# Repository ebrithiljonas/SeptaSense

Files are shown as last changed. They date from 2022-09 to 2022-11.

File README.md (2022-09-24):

# Septa Sense

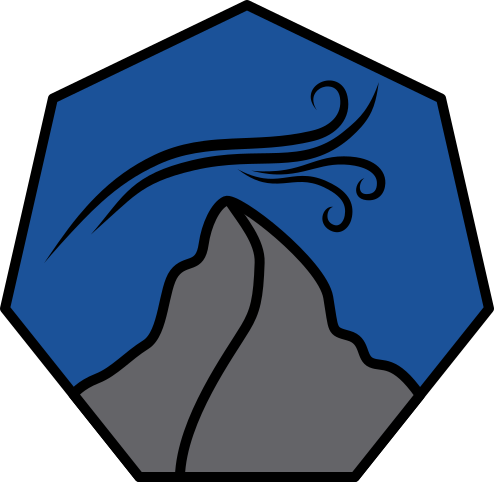
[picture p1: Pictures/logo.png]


Septa Sense in an Open Source and Open Hardware IoT air quality sensor, based on an ESP32 running ESPHome. It features a rim of RGB-LEDs around the top which indicate the quality of the air. Measurements can be seen either on in the integrated display or over Home Assistant. The unit is powered with a USB-C plug on the backside.

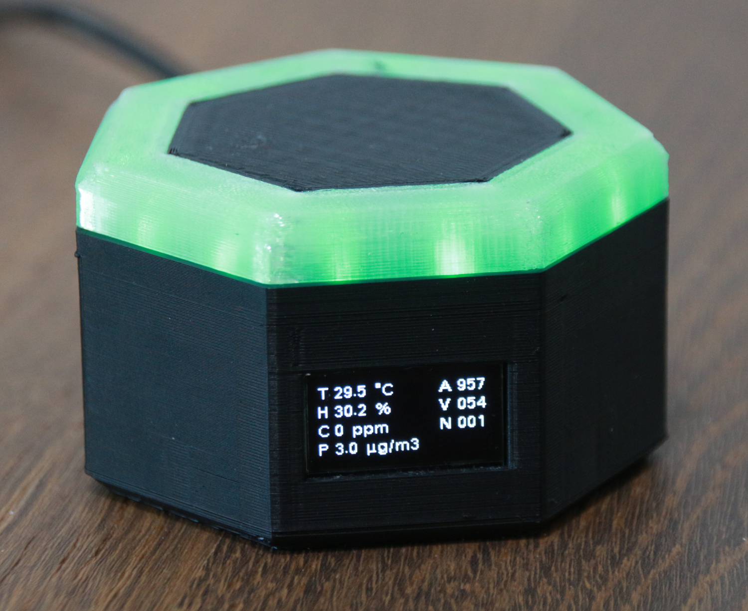
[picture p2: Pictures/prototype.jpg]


## Capabilities
- Temperature (0 - 50°C ± 0.5°C)
- Humidity (0 - 100% ± 4.5%)
- VOC (1 - 500 Index ± 5 Index)
- NOx (1 - 500 Index ± 10 Index)
- Particulate Matter (0 - 1000 μg/m³ ± 10%)
- CO2 (400 - 5000 ppm ± (40 ppm + 5%))
- Pressure (300 - 1250 hPa ± 0.5 hPa)

### Sensors
- [SEN55](https://sensirion.com/products/catalog/SEN55/)
- [SCD41](https://sensirion.com/products/catalog/SCD41/)
- [BMP388](https://www.bosch-sensortec.com/products/environmental-sensors/pressure-sensors/bmp388/)

## Mainboard

The mainboard is a custom PCB which holds the ESP32 chip, the BMP388 and SCD41 sensors and the RGB LEDs. The SEN55 sensor and the display are connected to it with a cable that is directly soldered to the board. It gets power via the USB-C plug over a cable with a JST XH connector that is mounted on the PCB.

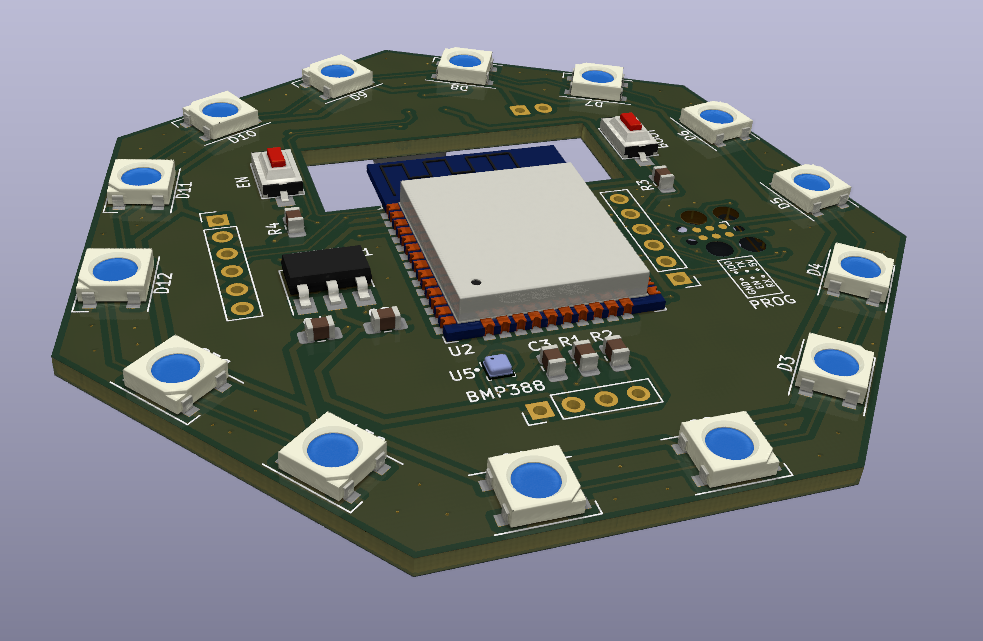
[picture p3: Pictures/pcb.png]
pcb


## 3D-Print

The case consists of 5 different 3D printed parts. Recommended print settings are:

- Case Bottom
  - Layer height: 0.2 mm
  - Infill: 10 %
  - Support: Yes
  - Support overhang: 80°
- Case Top
  - Layer height: 0.2 mm
  - Infill: 10 %
  - Support: No
- LED Ring
  - Layer height: 0.2 mm
  - Infill: 20 %
  - Support: No
- SEN55 Bracket
  - Layer height: 0.1 mm
  - Infill: 20 %
  - Support: No
- Display Fixture
  - Layer height: 0.2 mm
  - Infill: 20 %
  - Support: No

## BOM
- 1x [Mainboard](#mainboard)
- 1x [SEN55](https://sensirion.com/products/catalog/SEN55/)
- 1x [SCD41](https://sensirion.com/products/catalog/SCD41/)
- 1x Display [SD1306 128x64](https://www.aliexpress.com/item/32638662748.html)
- 1x [USB-C Connector](https://www.aliexpress.com/item/1005001714874457.html)
- 1x Micro JST GH 6 pin Cable
- 1x JST XH 2 Pin Cable
- 1x Dupont Female 4 pin Cable
- 2x M3x5,7-OD 4,6 heat inserts
- 2x M3x10 countersunk screws
- 1x [Set of 3D-Prints](#3d-print)

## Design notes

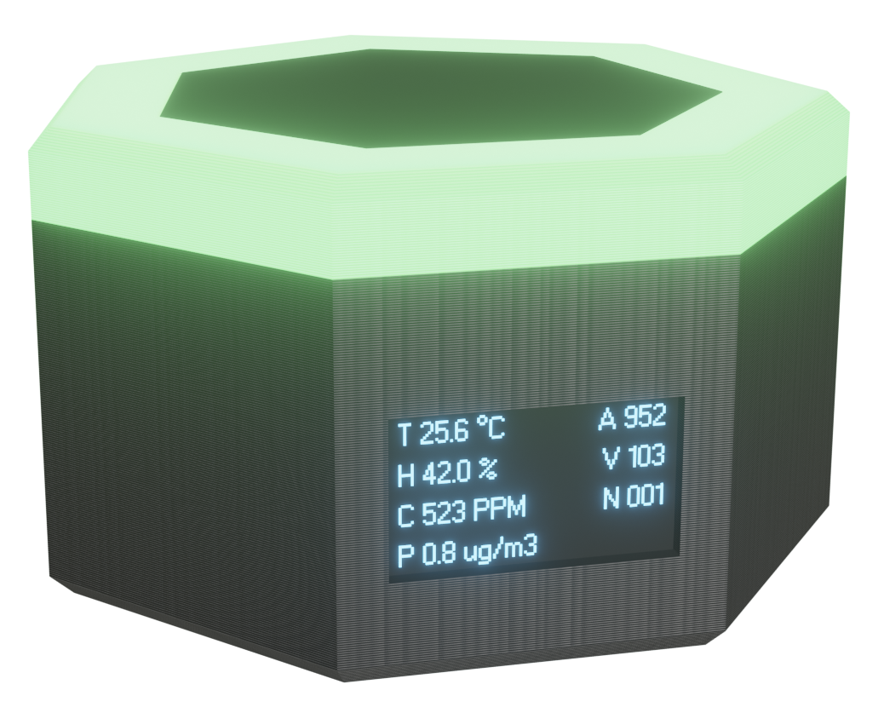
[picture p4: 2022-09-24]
Pictures/render.png

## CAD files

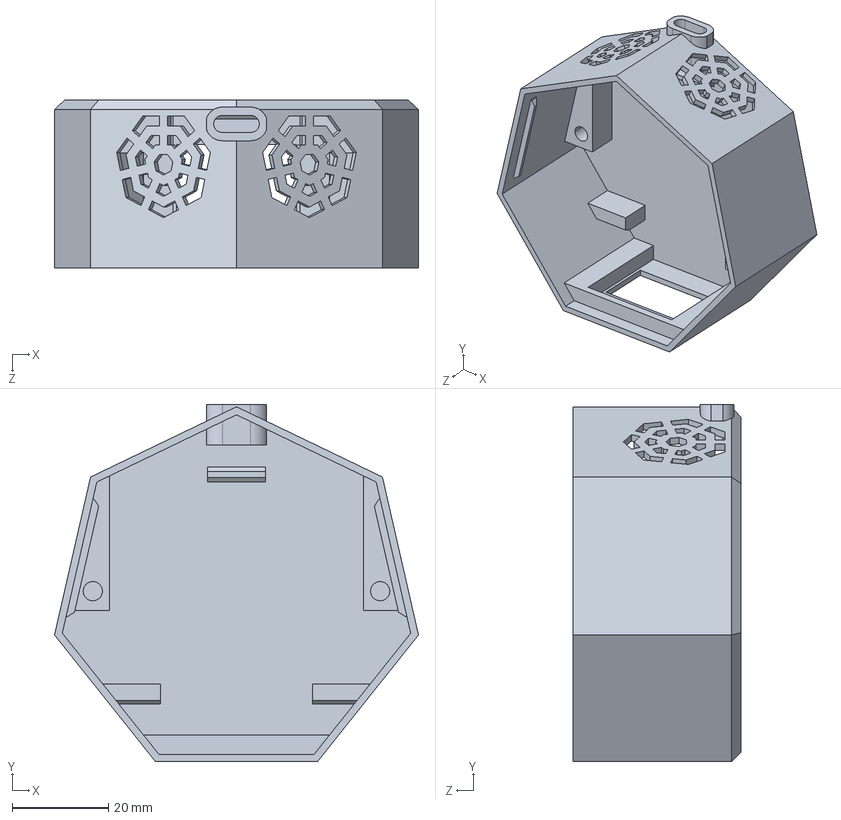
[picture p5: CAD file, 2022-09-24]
CAD/Case Bottom.STEP
75.7 x 74.3 x 35.0 mm

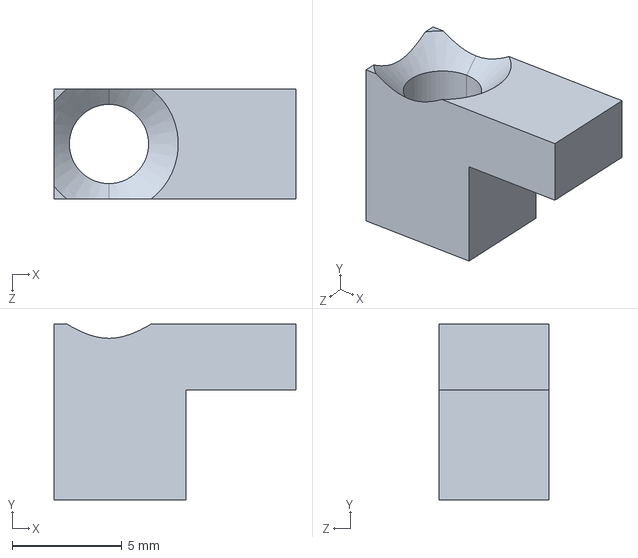
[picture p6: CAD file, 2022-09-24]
CAD/SEN55 Bracket.STEP
11.0 x 8.00 x 5.00 mm

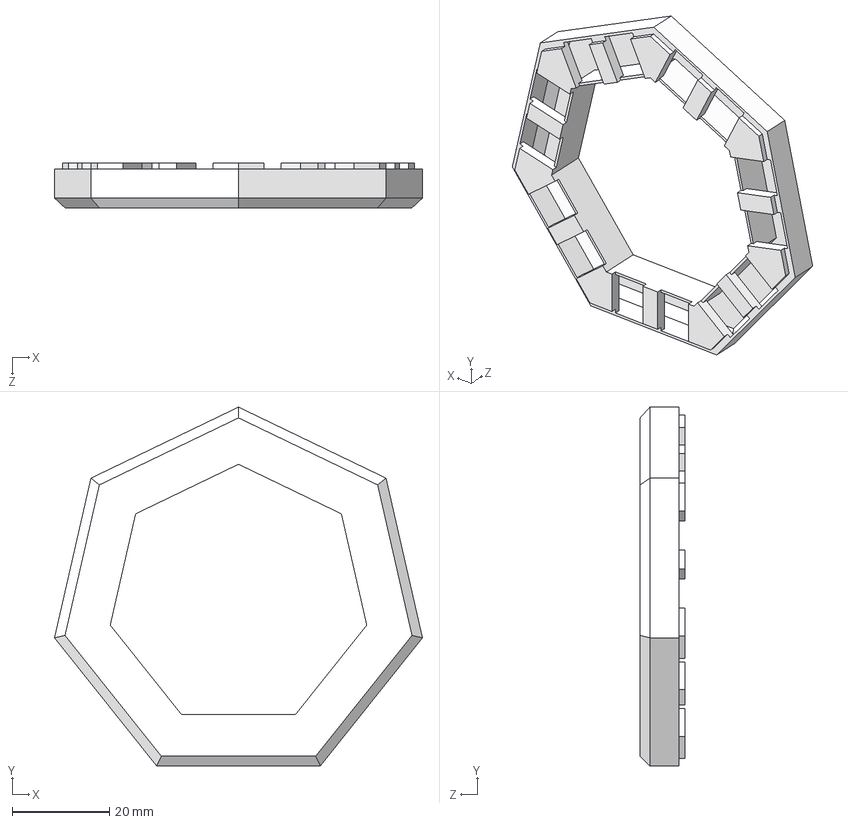
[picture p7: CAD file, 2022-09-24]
CAD/Case Top LED-Ring.STEP
75.7 x 73.8 x 9.20 mm

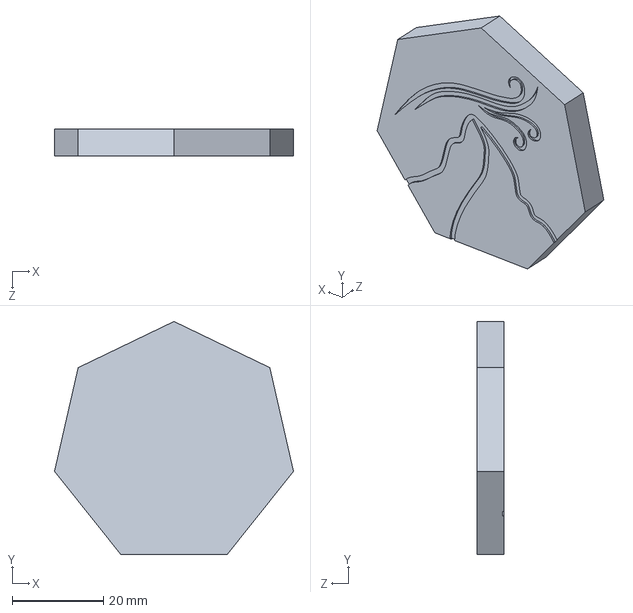
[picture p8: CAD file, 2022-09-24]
CAD/Case Top Logo.STEP
52.4 x 51.1 x 6.00 mm

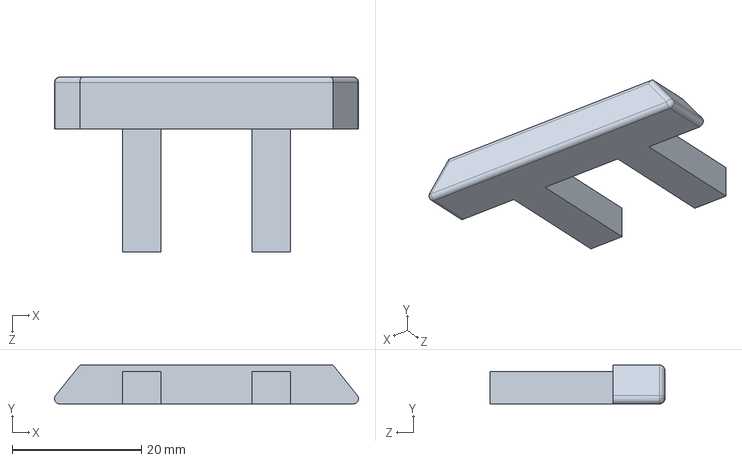
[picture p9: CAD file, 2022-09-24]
CAD/Display Fixture.STEP
47.0 x 6.00 x 27.0 mm

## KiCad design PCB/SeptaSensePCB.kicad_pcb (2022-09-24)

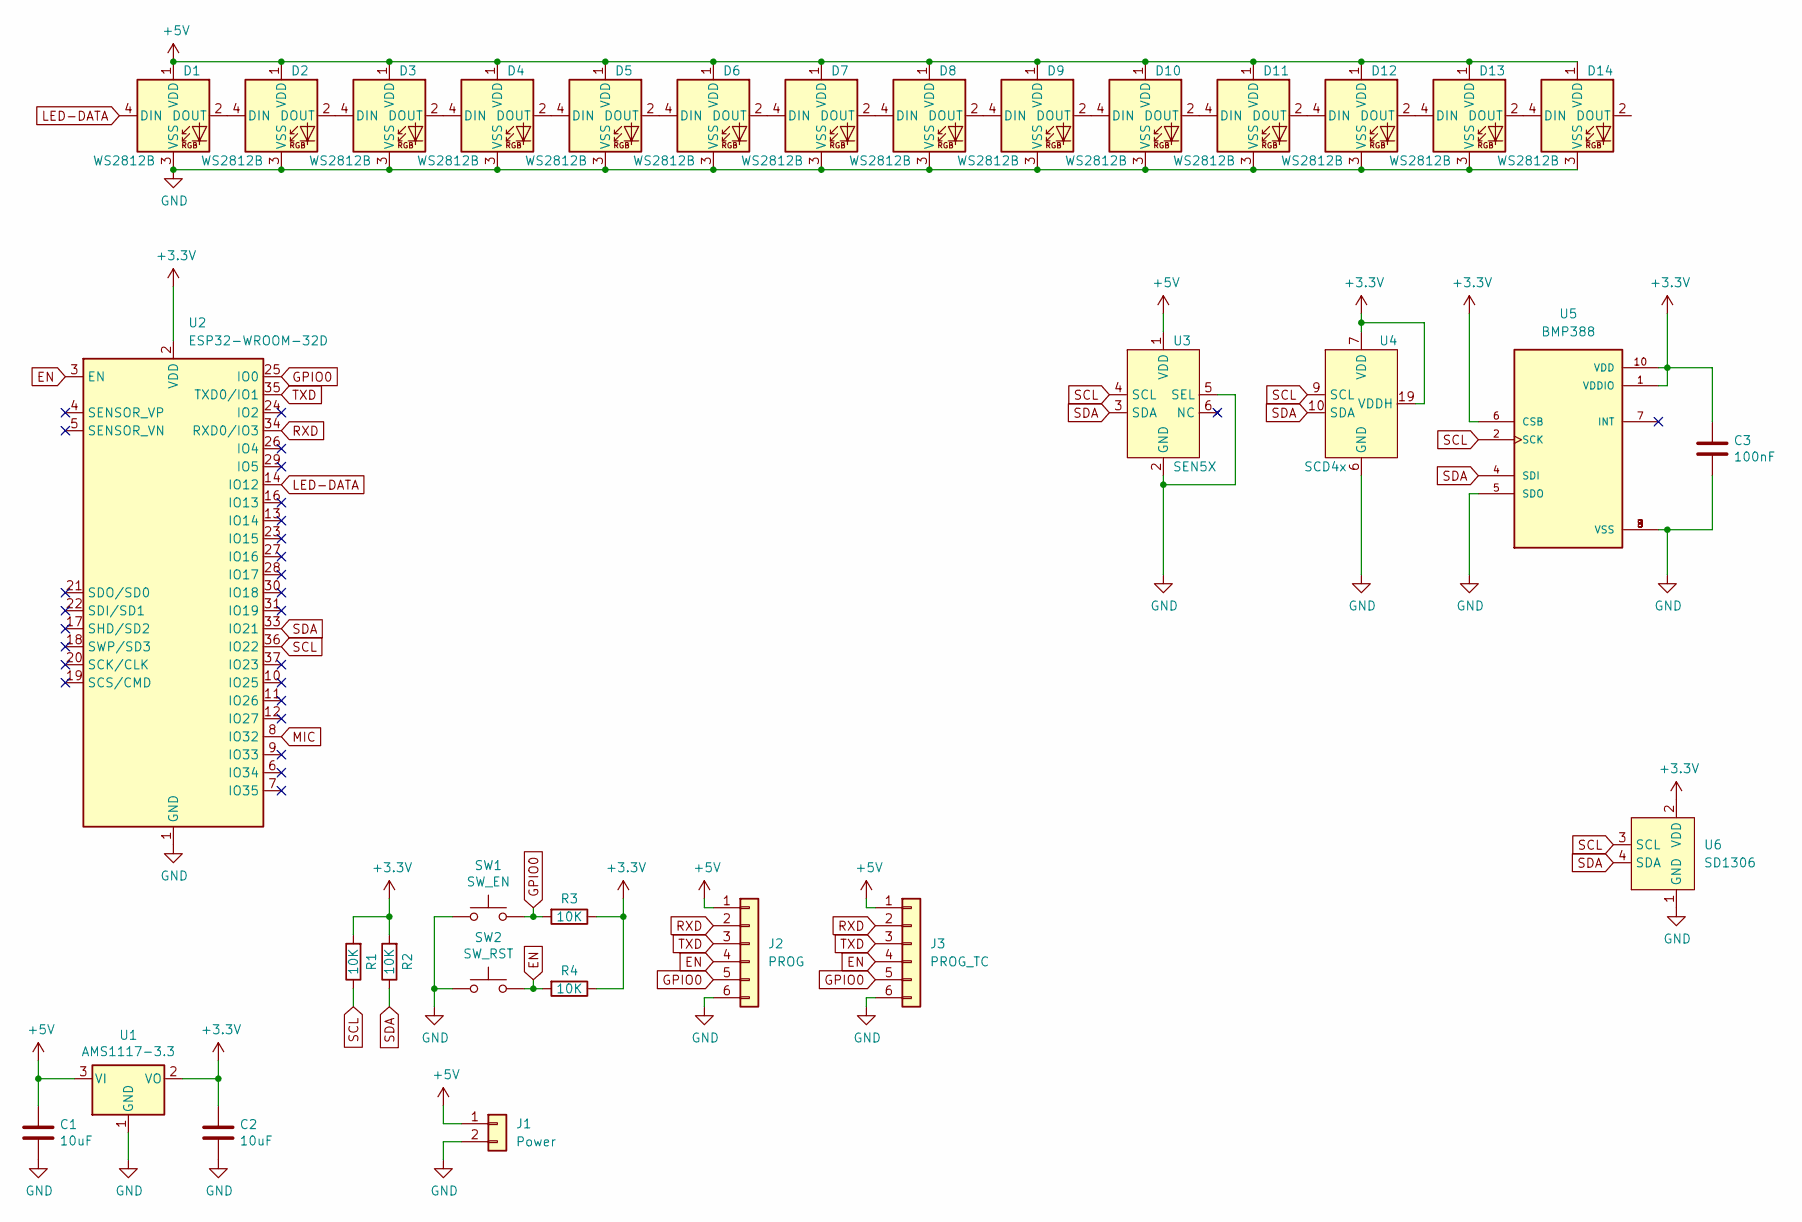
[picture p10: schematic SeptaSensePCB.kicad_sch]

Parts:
C1, C2: 10uF; C_0805_2012Metric_Pad1.18x1.45mm_HandSolder; LCSC C17024
C3: 100nF; C_0805_2012Metric_Pad1.18x1.45mm_HandSolder; LCSC C1711
D1, D2, D3, D4, D5, D6, D7, D8, D9, D10, D11, D12, D13, D14: WS2812B; LED_WS2812B_PLCC4_5.0x5.0mm_P3.2mm; JLC SMD,5x5mm
J1: Power; JST_XH_B2B-XH-A_1x02_P2.50mm_Vertical
J2: PROG; PinHeader_1x06_P2.54mm_Vertical
J3: PROG_TC; Tag-Connect_TC2030-IDC-FP_2x03_P1.27mm_Vertical
R1, R2, R3, R4: 10K; C_0805_2012Metric_Pad1.18x1.45mm_HandSolder; JLC 0805
SW1: SW_EN; SW_SPST_CK_RS282G05A3; JLC KEY-SMD
SW2: SW_RST; SW_SPST_CK_RS282G05A3; JLC KEY-SMD
U1: AMS1117-3.3; SOT-223-3_TabPin2; JLC SOT-223
U2: ESP32-WROOM-32D; ESP32-WROOM-32; LCSC C473012
U3: SEN5X; PinHeader_1x06_P2.54mm_Vertical
U4: SCD4x; Sensirion_SCD4x_10.1x10.x_P1.0mm
U5: BMP388; PQFN50P200X200X80-10N; PARTREV 1.1; LCSC C779278
U6: SD1306; PinHeader_1x04_P2.54mm_Vertical

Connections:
+3V3: C2.1, C3.1, R1.2, R2.2, R3.1, R4.1, U1.2 (VO), U2.2 (VDD), U4.7 (VDD), U4.19 (VDDH), U5.1 (VDDIO), U5.6 (CSB), U5.10 (VDD), U6.2 (VDD)
+5V: C1.1, D1.1 (VDD), D2.1 (VDD), D3.1 (VDD), D4.1 (VDD), D5.1 (VDD), D6.1 (VDD), D7.1 (VDD), D8.1 (VDD), D9.1 (VDD), D10.1 (VDD), D11.1 (VDD), D12.1 (VDD), D13.1 (VDD), D14.1 (VDD), J1.1, J2.1, J3.1, U1.3 (VI), U3.1 (VDD)
EN: J2.4, J3.4, R4.2, SW2.2, U2.3 (EN)
GND: C1.2, C2.2, C3.2, D1.3 (VSS), D2.3 (VSS), D3.3 (VSS), D4.3 (VSS), D5.3 (VSS), D6.3 (VSS), D7.3 (VSS), D8.3 (VSS), D9.3 (VSS), D10.3 (VSS), D11.3 (VSS), D12.3 (VSS), D13.3 (VSS), D14.3 (VSS), J1.2, J2.6, J3.6, SW1.1, SW2.1, U1.1 (GND), U2.1 (GND), U2.15 (GND), U2.38 (GND), U2.39 (GND), U3.2 (GND), U3.5 (SEL), U4.6 (GND), U4.20 (GND), U4.21 (GND), U5.3 (VSS), U5.5 (SDO), U5.8 (VSS), U5.9 (VSS), U6.1 (GND)
GPIO0: J2.5, J3.5, R3.2, SW1.2, U2.25 (IO0)
LED-DATA: D1.4 (DIN), U2.14 (IO12)
MIC: U2.8 (IO32)
unnamed: D1.2 (DOUT), D2.4 (DIN)
unnamed: D2.2 (DOUT), D3.4 (DIN)
unnamed: D3.2 (DOUT), D4.4 (DIN)
unnamed: D4.2 (DOUT), D5.4 (DIN)
unnamed: D5.2 (DOUT), D6.4 (DIN)
unnamed: D6.2 (DOUT), D7.4 (DIN)
unnamed: D7.2 (DOUT), D8.4 (DIN)
unnamed: D8.2 (DOUT), D9.4 (DIN)
unnamed: D10.2 (DOUT), D11.4 (DIN)
unnamed: D9.2 (DOUT), D10.4 (DIN)
unnamed: D11.2 (DOUT), D12.4 (DIN)
unnamed: D12.2 (DOUT), D13.4 (DIN)
unnamed: D13.2 (DOUT), D14.4 (DIN)
RXD: J2.2, J3.2, U2.34 (RXD0/IO3)
SCL: R1.1, U2.36 (IO22), U3.4 (SCL), U4.9 (SCL), U5.2 (SCK), U6.3 (SCL)
SDA: R2.1, U2.33 (IO21), U3.3 (SDA), U4.10 (SDA), U5.4 (SDI), U6.4 (SDA)
TXD: J2.3, J3.3, U2.35 (TXD0/IO1)

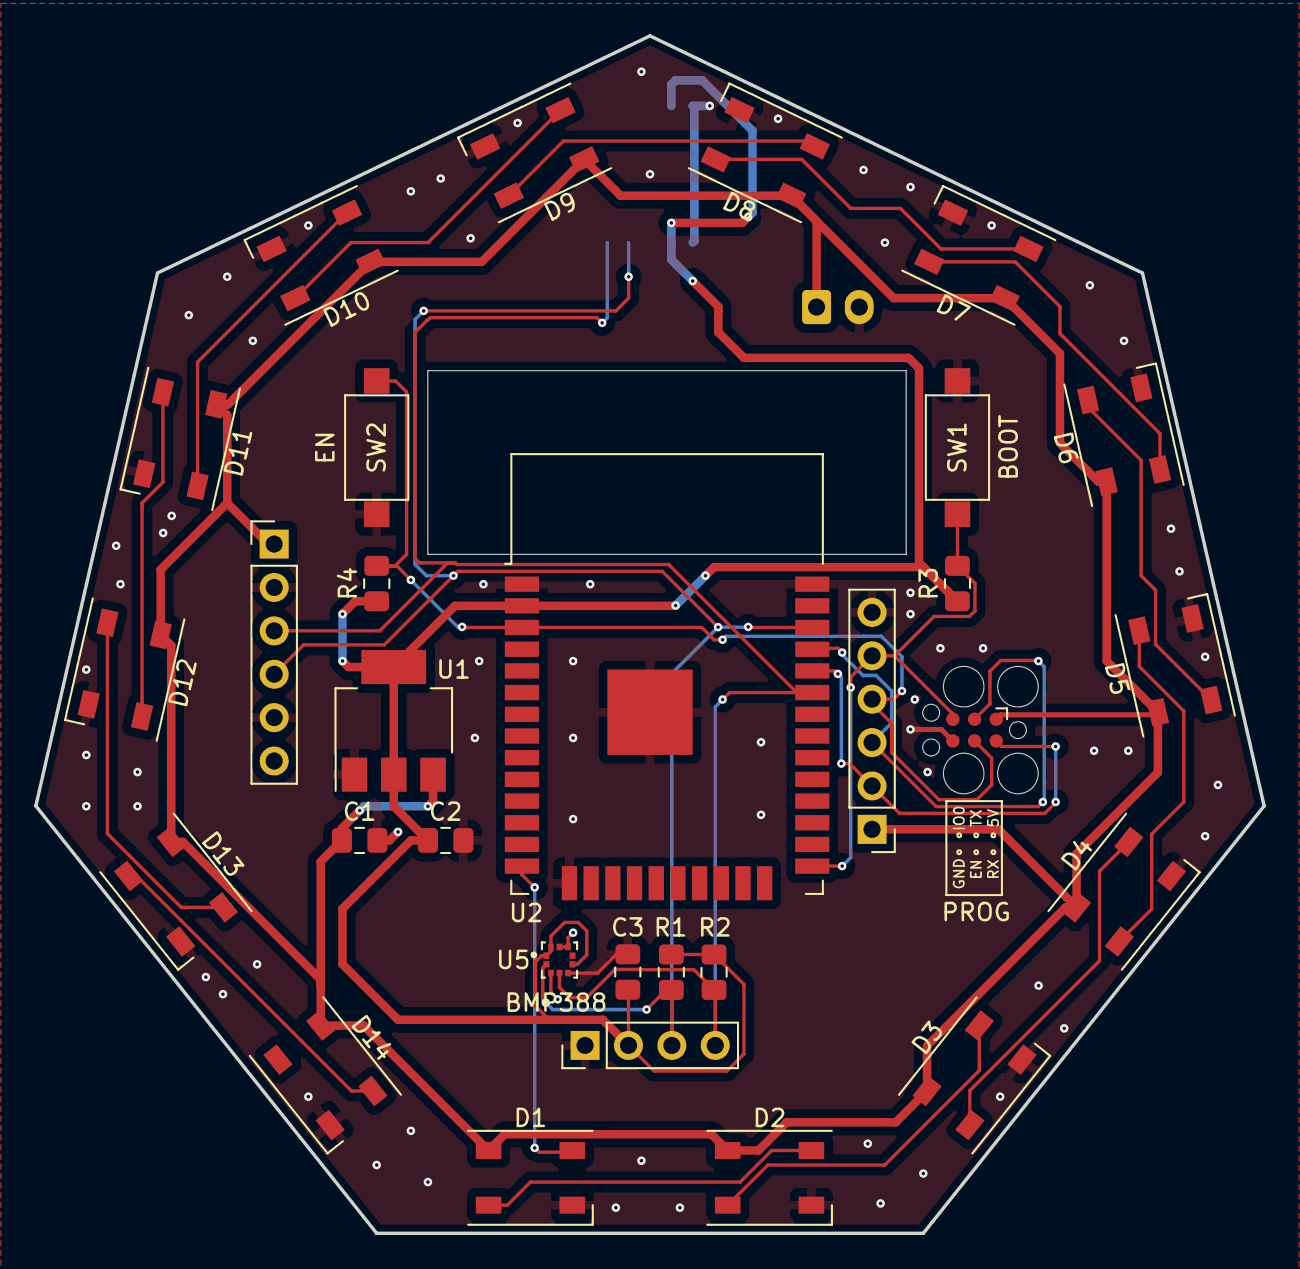
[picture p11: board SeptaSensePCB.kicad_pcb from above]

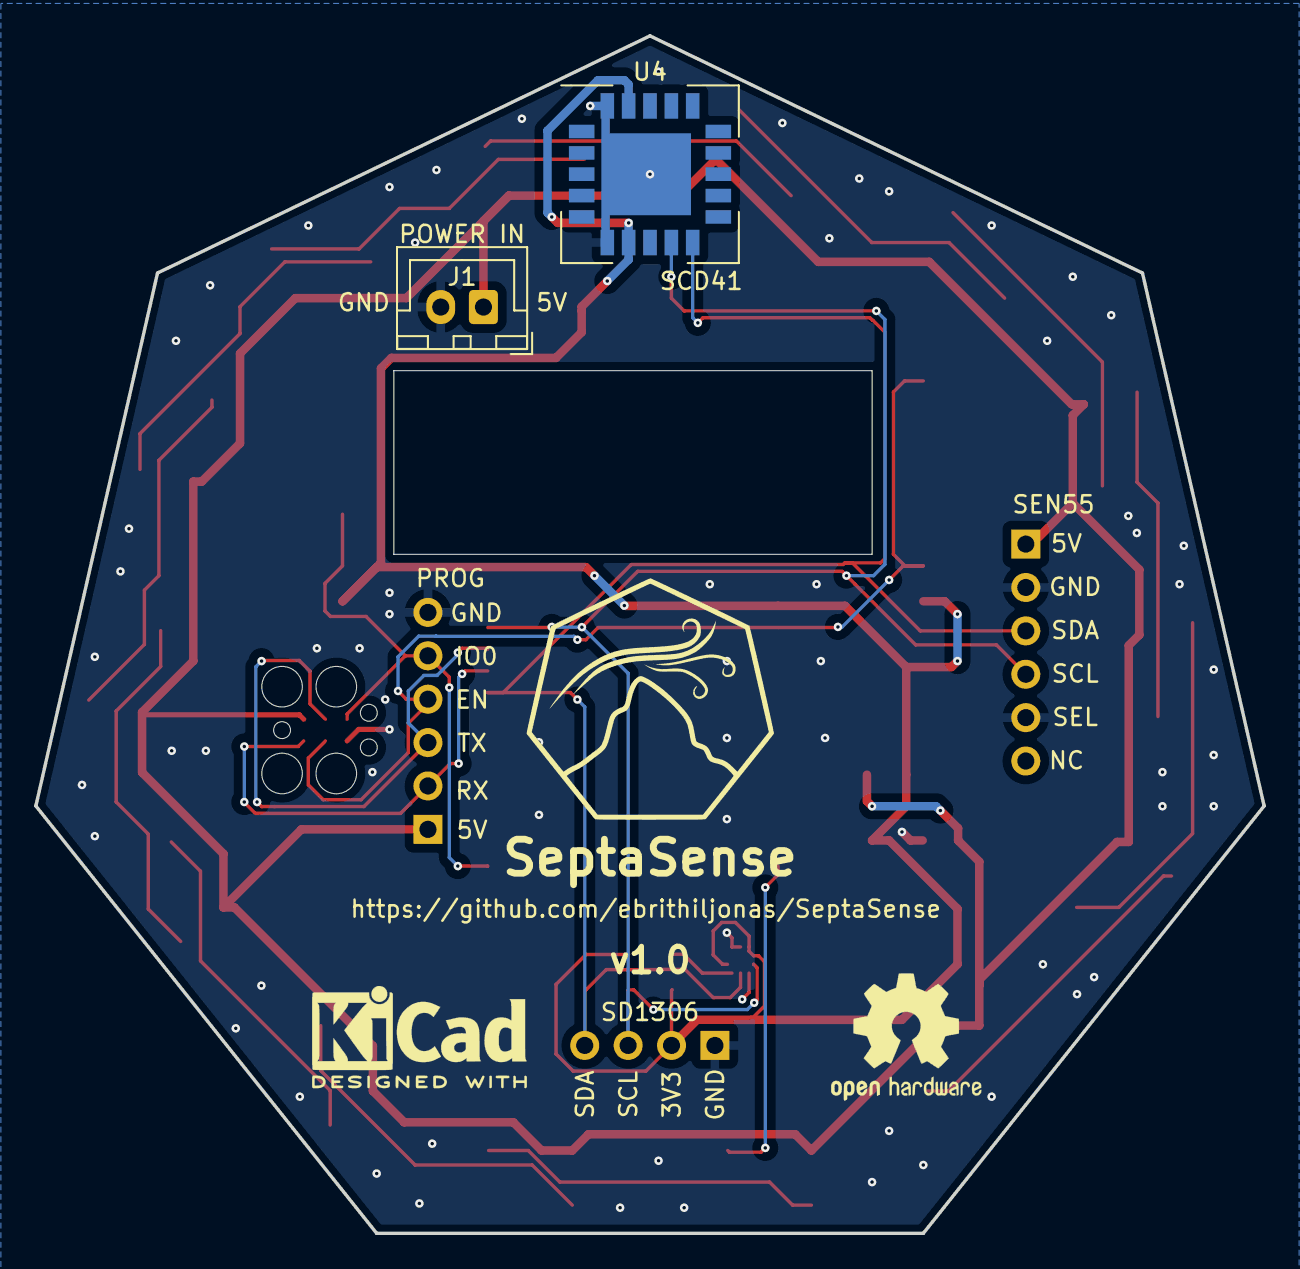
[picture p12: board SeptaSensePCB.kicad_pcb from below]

Board: 2 copper layers, 71.9 x 70.1 mm, 32 parts (2 on the bottom side), 23 nets.

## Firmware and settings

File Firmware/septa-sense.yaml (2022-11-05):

substitutions:
  # Name
  name: "septa-sense"
  sensor_prefix: "SeptaSense"
  # Sensor Warnings/Limits
  warning_pm_2_5: "12.0"
  limit_pm_2_5: "25.0"
  warning_pm_10_0: "20.0"
  limit_pm_10_0: "40.0"
  warning_co2: "800.0"
  limit_co2: "1500.0"
  warning_voc: "150.0"
  limit_voc: "250.0"
  warning_nox: "20.0"
  limit_nox: "150.0"
  
  default_pw: "8AVrcPLTDWBz"

esphome:
  name: ${name}
  name_add_mac_suffix: true
  comment: "SeptaSense Air Quality Sensor"
  project:
    name: ebrithil.septa-sense
    version: "1.1"
  on_boot:
    - script.execute: startup
  
esp32:
  board: esp32dev
  
wifi:
  # ssid: !secret wifi_ssid
  # password: !secret wifi_password
  ap:
    password: ${default_pw}

captive_portal:

dashboard_import:
  package_import_url: github://ebrithiljonas/SeptaSense/Firmware/septa-sense.yaml

logger:
  level: INFO
api:
  password: ${default_pw}
ota:
  password: ${default_pw}
  on_begin:
    then:
      - display.page.show: page_ota
      - light.addressable_set:
          id: air_quality_lights
          red: 0%
          green: 0%
          blue: 0%
  on_progress:
    then:
      - globals.set:
          id: ota_progress
          value: !lambda return x;
      - script.execute: ota_progress_update
      - component.update: display_main
      
i2c:
  sda: 21
  scl: 22
  
light:
  - platform: fastled_clockless
    id: air_quality_lights
    chipset: WS2812B
    pin: 12
    num_leds: 14
    rgb_order: GRB
    name: Lights
    restore_mode: ALWAYS_OFF
    internal: true

sensor:
  - platform: sen5x
    id: sen55
    pm_1_0:
      name: "${sensor_prefix} PM <1µm"
      id: sensor_pm_1_0
      accuracy_decimals: 1
      filters:
        - median:
            window_size: &window_size 15
            send_every: &send_every 15
            send_first_at: &send_first_at 15
      on_value:
        then:
          - script.execute: update
    pm_2_5:
      name: "${sensor_prefix} PM <2.5µm"
      id: sensor_pm_2_5
      accuracy_decimals: 1
      filters:
        - median:
            window_size: *window_size
            send_every: *send_every
            send_first_at: *send_first_at
    pm_4_0:
      name: "${sensor_prefix} PM <4µm"
      id: sensor_pm_4_0
      accuracy_decimals: 1
      filters:
        - median:
            window_size: *window_size
            send_every: *send_every
            send_first_at: *send_first_at
    pm_10_0:
      name: "${sensor_prefix} PM <10µm"
      id: sensor_pm_10_0
      accuracy_decimals: 1
      filters:
        - median:
            window_size: *window_size
            send_every: *send_every
            send_first_at: *send_first_at
    temperature:
      name: "${sensor_prefix} Temperature"
      id: sensor_temperature
      accuracy_decimals: 1
      filters:
        - calibrate_linear:
          - 10.25 -> 9.31
          - 51.63 -> 49.91
        - offset: -1.0
    humidity:
      name: "${sensor_prefix} Humidity"
      id: sensor_humidity
      accuracy_decimals: 0
      filters:
        - median:
            window_size: *window_size
            send_every: *send_every
            send_first_at: *send_first_at
    voc:
      name: "${sensor_prefix} VOC"
      id: sensor_voc
      filters:
        - median:
            window_size: *window_size
            send_every: *send_every
            send_first_at: *send_first_at
    nox:
      name: "${sensor_prefix} NOx"
      id: sensor_nox
      filters:
        - median:
            window_size: *window_size
            send_every: *send_every
            send_first_at: *send_first_at
    temperature_compensation:
      offset: 0.0
      normalized_offset_slope: 0
      time_constant: 0
    acceleration_mode: high
    store_baseline: true
    address: 0x69
    update_interval: 1s

  - platform: scd4x
    co2:
      name: "${sensor_prefix} CO2"
      id: sensor_co2
      accuracy_decimals: 0
      filters:
        - median:
            window_size: 5
            send_every: 2
            send_first_at: 2
    ambient_pressure_compensation_source: sensor_pressure
    address: 0x62
    update_interval: 10s

  - platform: bmp3xx
    pressure:
      name: "${sensor_prefix} Pressure"
      id: sensor_pressure
      accuracy_decimals: 0
      filters:
        - median:
            window_size: 10
            send_every: 10
            send_first_at: 10
    address: 0x76
    update_interval: 10s
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
